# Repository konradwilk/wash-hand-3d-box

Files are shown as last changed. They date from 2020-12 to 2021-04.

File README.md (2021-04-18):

# License

The project is under Attribution-ShareAlike 4.0 International (CC BY-SA 4.0).

# Purpose

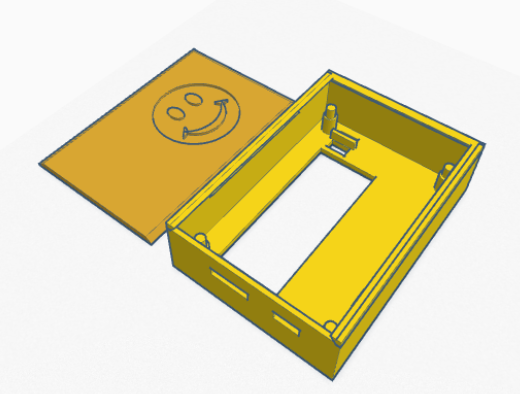
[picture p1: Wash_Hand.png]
-

Enclosure for the Wash Hand PCB board.
See  <a href="https://github.com/konradwilk/wash-hand-pcb">https://github.com/konradwilk/wash-hand-pcb</a>

# Files

 - *LICENSE.txt* - CC BY-SA 4.0 license file.
 - *Wash_Hand_dim.stl* is retrieved from <a href="https://github.com/konradwilk/wash-hand-pcb/blob/main/3d/Wash_Hand_dim.stl">
   Wash_Hand_dim.stl</a> which is a representation of the PCB board along with the various outlines.
   This can be used to construct a box around it.
 - *Happy_Face.(stl,scad,svg)* - Inkscript generated Happy Face because 2021 is coming!
 - *Body|Lid.(stl,gobject,png)* - The enclosure parts

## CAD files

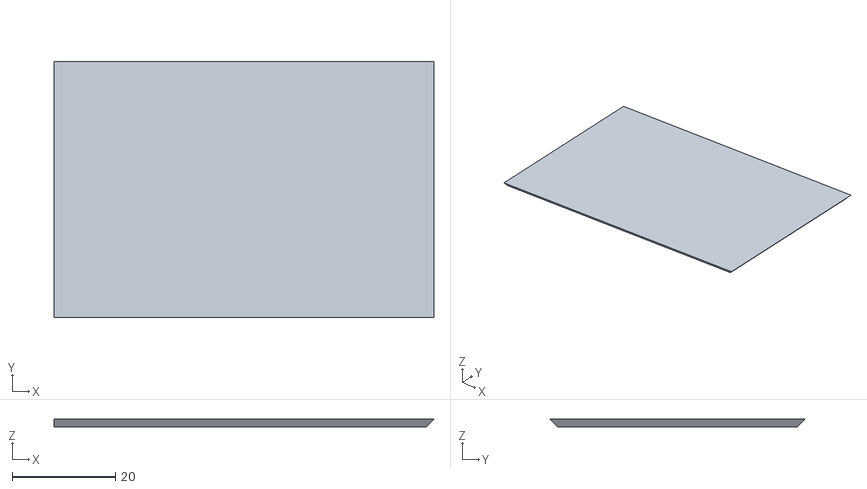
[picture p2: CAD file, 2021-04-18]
Lid v10 v3.stl
73.6 x 49.5 x 1.50

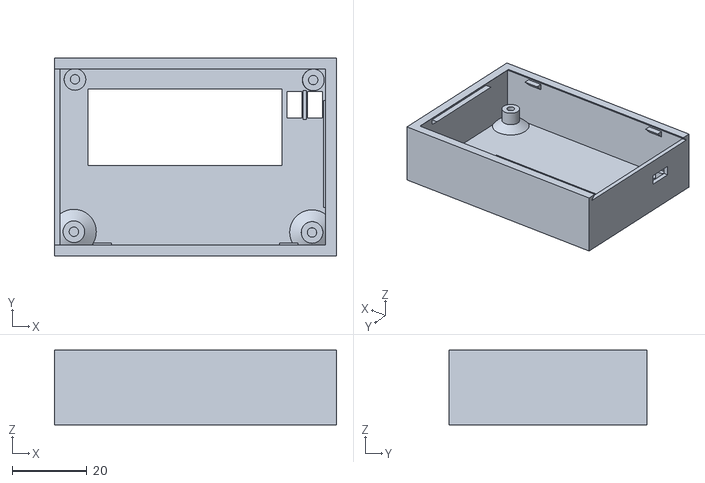
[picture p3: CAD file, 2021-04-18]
Body v15 v1.stl
75.5 x 53.0 x 20.0

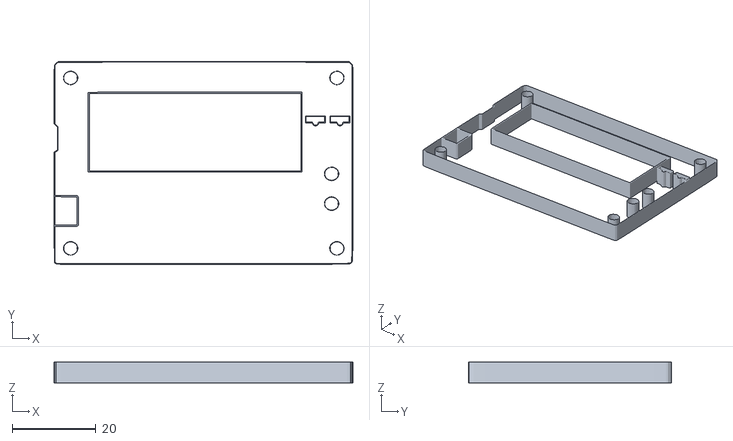
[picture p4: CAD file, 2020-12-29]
Wash_Hand_dim.stl
71.3 x 48.4 x 5.00

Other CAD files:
Body v15 v1.f3d
Lid v10 v3.f3d

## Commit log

2020-12-29 README and Wash Hand PCB outline
    [Wash_Hand_dim.stl]
2020-12-30 box: v4 of the design
    There are some issues:
    - The USB and SD-card are too high
    - The openning for the LCD is to cramped
    - The columns for the holes is way too high
    - The holes for the IR detector/emitter are assuming
    that emitter is at the top, but it is not.
    [Wash_Hand.stl]
2020-12-30 box: v6 - dimensions are all good.
    This enclosure fits the PCB snuggly and is all good.
    Now it has a glaring issue - no lid.
    [Wash_Hand.stl]
2020-12-30 box: v8: Enclosure with a slide + Happy Face
    And a little lid right under where the lid is going to be.
    [Happy_Face.scad, Happy_Face.stl, Wash_Hand.stl]
2020-12-30 box: v8: Enclosure + Lid
    so that both can be printed.
    [Wash_Hand.stl]
2020-12-30 v8: Change the lip to be a wedge.
    Lets see how well this will work and whether it will stick.
    [Wash_Hand.stl]
2020-12-30 box: v8 add another lip on the other side
    .. but it cannot be for the full width as the
    PCB board won't be able to fit in. Hence putting
    little lips and lets see if we can fit the PCB in.
    (Or alternatively we can make cuts in the PCB?)
    [Wash_Hand.stl]
2021-01-02 v8: Remove the v1.4.8 text and replace smiley ..
    with one from www.thingiverse.com/thing:2197219
    and may as well remove the ones we created.
    [Happy_Face.scad, Happy_Face.stl, Wash_Hand.stl]
2021-01-02 v8: A box only without the SD card slot
    .. as most of the boards won't have it working
    due to the PCB having the slots too far on
    the board.
    [Wash_Hand_NOSD.stl]
2021-04-18 Import the Autodesk 360 files and STL files.
    [Body v15 v1.f3d, Body v15 v1.stl, Lid v10 v3.f3d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]
